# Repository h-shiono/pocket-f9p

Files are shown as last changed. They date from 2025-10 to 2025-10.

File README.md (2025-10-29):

# 📡 Pocket-F9P

`Pocket-F9P` is a pocketable, all-in-one high-precision GNSS (F9P) receiver with a battery, data logger, and BLE (NTRIP) interface.

> [!IMPORTANT]
> ⚠️ We shall not be held responsible for any damage or loss incurred as a result of actions taken based on the information contained in this repository. 

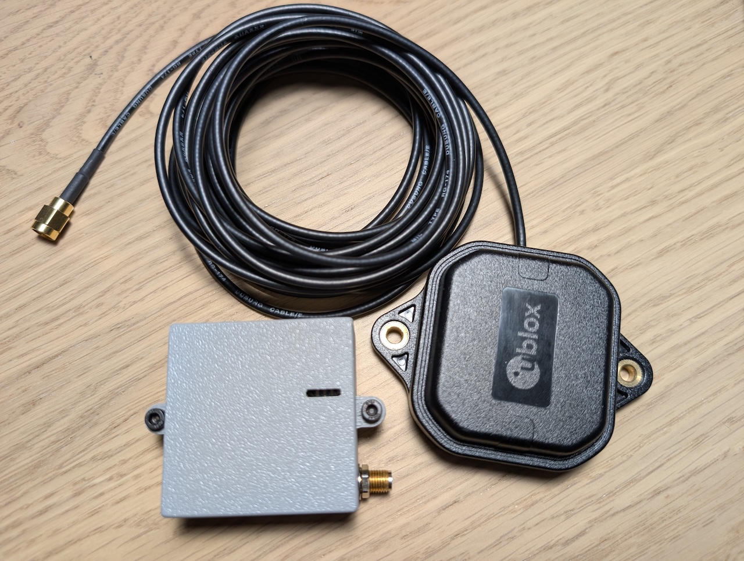
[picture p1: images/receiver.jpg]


[🇯🇵 README](README_jp.md)

## 🚀　Overview

- **Battery Driven, Compact, High-Accuracy GNSS Receiver:** Designed the compact (Approx. 48 mm x 48 mm x 22 mm) GNSS receiver to improve the usability of u-blox F9P, with Micro SD logger, communication and battery
- **Supports correction input via BLE:** By combining with the smartphone application such as `GNSS Master`, the receiver can utilize the correction data via `NTRIP`
- **Customizable microcontroller:** The microcontroller `Seeeduino XIAO` is utilized for the communication, so it’s easy to customize the application for user-dedicated objectives

**Important notes for use**
> [!WARNING]
> When you connect to the F9P usb port, you have to switch the hw switch `off`.
> The boards (`XIAO ESP32C`, `u-blox F9P` or both) will be damaged.

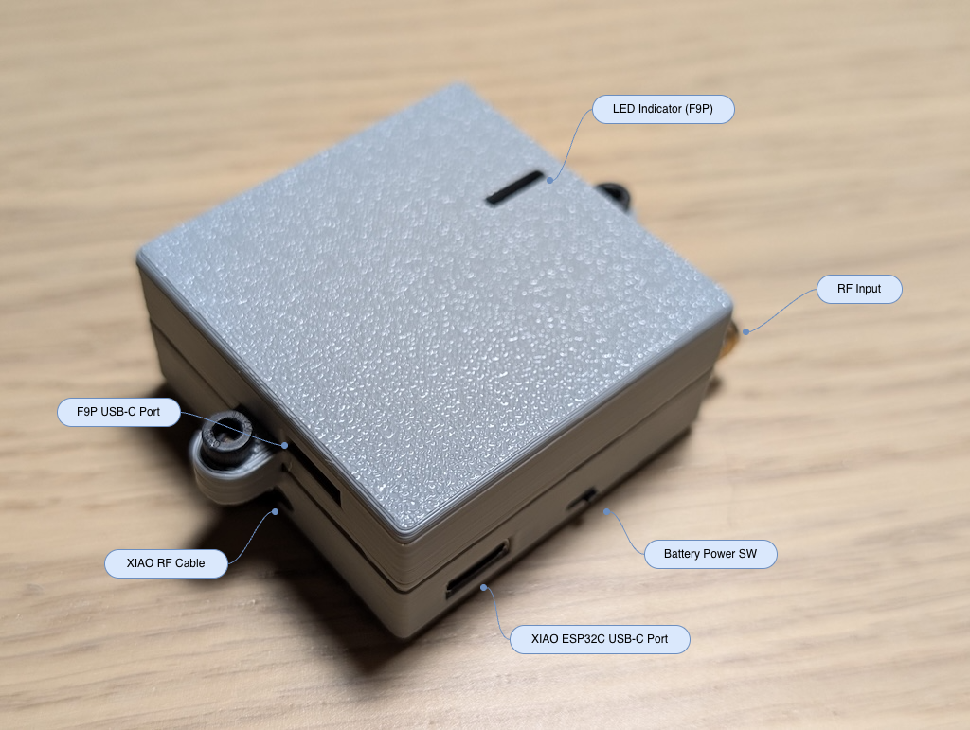
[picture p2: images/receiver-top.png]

<br>
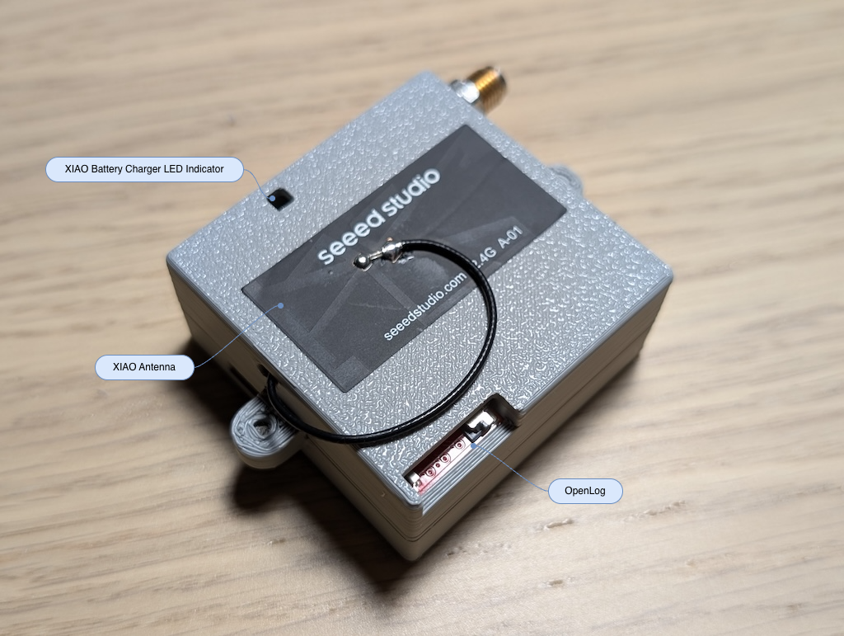
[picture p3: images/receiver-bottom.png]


## ⚙️ Setup

This section describes how to setup the receiver.

### Hardware

##### Parts list

Parts                                                                                                                       |Qty|Description
----------------------------------------------------------------------------------------------------------------------------|---|-----------
[SparkFun GPS-RTK2 Board - ZED-F9P (Qwiic)](https://www.sparkfun.com/sparkfun-gps-rtk2-board-zed-f9p-qwiic-gps-15136.html)  |1  |GNSS Receiver
[Seeeduino XIAO ESP32C](https://www.seeedstudio.com/Seeed-XIAO-ESP32C3-p-5431.html)                                         |1  |Battery charger and BLE/NTRIP Interface
[SparkFun OpenLog](https://www.sparkfun.com/sparkfun-openlog.html)                                                          |1  |Micro SD Logger
[DATA POWER TECHNOLOGY DTP652533](https://www.sengoku.co.jp/mod/sgk_cart/detail.php?code=EEHD-67JP)                         |1  |Battery
SMA to U.FL Cable                                                                                                           |1  |SMA <-> U.FL Conversion
[NKK Switches SS-12SDP2](https://www.nkkswitches.co.jp/product/detailed/SS-12SDP2.html)                                     |1  |HW Switch
M3 x 5                                                                                                                      |2  |To secure the case
M3 x 25                                                                                                                     |4  |**Optional, Recommended** To secure the exoskeleton
M3 Nut                                                                                                                      |4  |**Optional, Recommended** To secure the exoskeleton

> [!NOTE]
> We utilized [SwitchScience ZED-F9P搭載GPS-RTKピッチ変換基板](https://www.switch-science.com/products/10511?_pos=4&_sid=bce749730&_ss=r) receiver for the prototyping.

#### Print the case

This repository provides two case options:

**v0.1.0 (Standard)**
The original compact case. *Note: The BLE antenna is exposed.*

- [Pocket-F9P-Top.3mf](case/Pocket-F9P-Top.3mf): Upper (F9P)
- [Pocket-F9P-Center.3mf](case/Pocket-F9P-Center.3mf): Center frame
- [Pocket-F9P-Bottom.3mf](case/Pocket-F9P-Bottom.3mf): Bottom (Logger, XIAO, Battery, HW Switch)

**v0.2.0 (with Exoskeleton)**
Recommended. Includes an external frame to protect the BLE antenna and add robustness.

- [Pocket-F9P-Top.3mf](case/Pocket-F9P-Top.3mf): Upper (F9P)
- [Pocket-F9P-Center.3mf](case/Pocket-F9P-Center.3mf): Center frame
- [Pocket-F9P-Bottom.3mf](case/Pocket-F9P-Bottom.3mf): Bottom (Logger, XIAO, Battery, HW Switch)
- [Exoskeleton-Top.3mf](case/Exoskeleton-Top.3mf)
- [Exoskeleton-Bottom.3mf](case/Exoskeleton-Bottom.3mf)

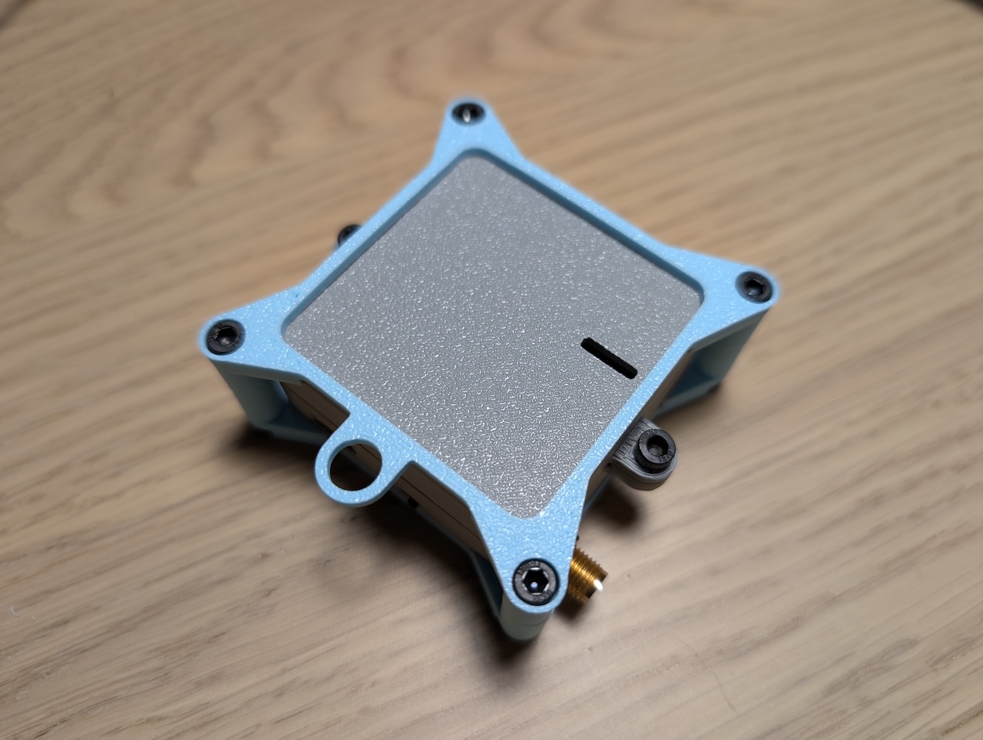
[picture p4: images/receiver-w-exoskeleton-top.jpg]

<br>
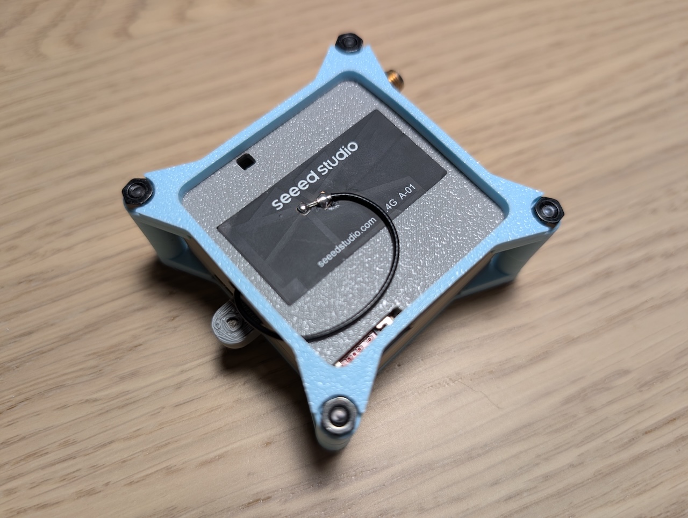
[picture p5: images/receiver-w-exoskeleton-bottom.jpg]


##### Wiring

Please refer to the following diagram and figure for wiring.

**Block Diagram**

```mermaid
graph TD

    sw[HW Switch]

    subgraph XIAO
        gnd_pad[GND Pad]
        vcc_pad[VCC Pad]
        d1["D1 (Tx)"]
        d2["D2 (Rx)"]
        xiao_vcc[3.3V]
        xiao_gnd[GND]
    end

    subgraph SW
        sw[SW] --- vcc_pad
    end

    subgraph Battery
        bat_minus[Bat -] --- gnd_pad
        bat_plus[Bat +] --- sw
    end

    subgraph Open-log
        ol_tx[Tx]
        ol_rx[Rx]
        ol_vcc[3.3V]
        ol_gnd[GND]
    end

    subgraph F9P-board
        tx_1[UART1 Tx] --- ol_rx
        rx_1[UART1 Rx] --- ol_tx
        tx_2[UART2 Tx] --- d2
        rx_2[UART2 Rx] --- d1
        f9_gnd[GND] --- ol_gnd 
        f9_vcc[3.3V] --- ol_vcc
        f9_gnd --- xiao_gnd
        f9_vcc --- xiao_vcc
    end
```

**Wiring Image**

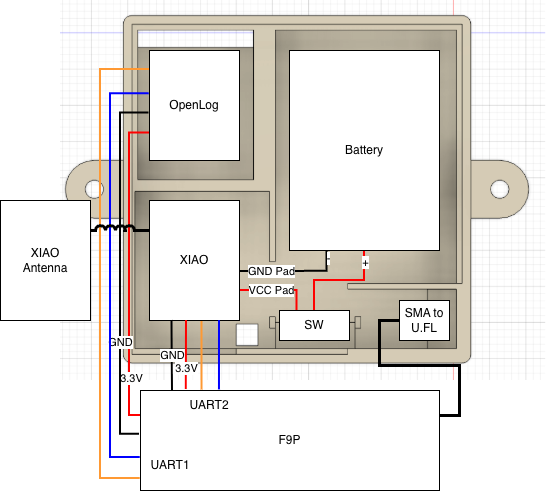
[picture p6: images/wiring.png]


#### Assembly

> [!CAUTION]
> We recommend [Write Firmware](#write-firmware) before assembling.

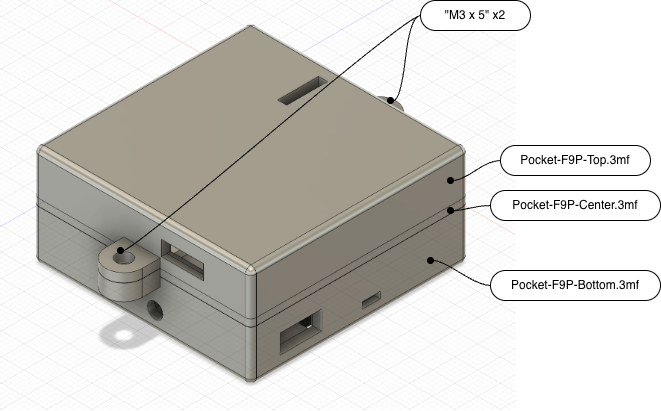
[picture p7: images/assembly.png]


### Software

#### Python setup

To setup the python environment, use uv:

```bash
cd pocket-f9p
uv sync
```

#### XIAO ESP32C

##### Write Firmware

1. **Download Firmware:** Download firmware from: [MicroPython ESP32-C3](https://micropython.org/download/ESP32_GENERIC_C3/), and move it to this directory
2. **Erase Flash:** Erase the flash by `erase-flash` option
3. **Write Firmware:** Then, write the binary which is downloaded in step 1 by `write-flash` option.

###### Erase Flash

```bash
% esptool --port /dev/cu.usbmodem1101 erase-flash 
sptool v5.1.0
Connected to ESP32-C3 on /dev/cu.usbmodem1101:
Chip type:          ESP32-C3 (QFN32) (revision v0.4)
Features:           Wi-Fi, BT 5 (LE), Single Core, 160MHz, Embedded Flash 4MB (XMC)
Crystal frequency:  40MHz
USB mode:           USB-Serial/JTAG
MAC:                94:a9:90:7a:07:f8

Stub flasher running.

Flash memory erased successfully in 14.9 seconds.

Hard resetting via RTS pin...
```

###### Write Firmware

```bash
% esptool --port /dev/cu.usbmodem1101 --baud 460800 write-flash 0 ESP32_GENERIC_C3-20250911-v1.26.1.bin
esptool v5.1.0
Connected to ESP32-C3 on /dev/cu.usbmodem1101:
Chip type:          ESP32-C3 (QFN32) (revision v0.4)
Features:           Wi-Fi, BT 5 (LE), Single Core, 160MHz, Embedded Flash 4MB (XMC)
Crystal frequency:  40MHz
USB mode:           USB-Serial/JTAG
MAC:                94:a9:90:7a:07:f8

Stub flasher running.
Changing baud rate to 460800...
Changed.

Configuring flash size...
Flash will be erased from 0x00000000 to 0x001cffff...
Wrote 1898384 bytes (1159203 compressed) at 0x00000000 in 14.3 seconds (1062.0 kbit/s).
Hash of data verified.

Hard resetting via RTS pin...
```

##### Write Script

After firmware writing, let's move on to the writing the application.

1. **Install Extension:** Install [MicroPico`](https://marketplace.visualstudio.com/items?itemName=paulober.pico-w-go) from MARKETPLACE
2. **Connect XIAO and Computer:** Connect XIAO and your computer with USB cable, then execute `Shift + >MicroPico: Connect` via `VS Code` command palette
3. **Write Script:** Open [main.py](src/pocket_f9p/main.py), then execute `Shift + >MicroPico: Upload file to pico` via command palette to upload the script to XIAO

#### u-blox F9P

The ports settings of F9P are as follows:

Target  |Protocol in            |Protocol out           |Baudrate   |Dest.
--------|-----------------------|-----------------------|-----------|-----
UART1   |0+1+5 - UBX+NMEA+RTCM3 |0+1+5 - UBX+NMEA+RTCM3 |115200     |Logger
UART2   |0+1+5 - UBX+NMEA+RTCM3 |**1 - NMEA**           |**38400**  |XIAO

> [!NOTE]
> - Our firmware supports **NMEA output only**
> - Set `1 - NMEA` for UART2 protocol out
>   - It is okay to set `0+1+5 - UBX+NMEA+RTCM3` for UART2 protocol out, however it's difficult to forward the whole data within 1 sec when using full GNSS constellations
> - We recommended the baudrate 38400bps, but the firmware can detect it automatically (supports 9600/38400/115200/57600/19200/230400 bps)

### 📱 Setup (Smartphone, Android)

#### Application (GNSS Master)

We utilized [GNSS Master](https://www.gnssmaster.com/) for this development.

##### GNSS Receiver Connection Setting

Tap ⚙️ on the right side of `GNSS Receiver Connection`, and set the following:

- **Mode:** `Bluetooth LE`
- **Paired Devices:** `Pocket-F9P`

##### Correction Input Setting

Tap ⚙️ on the right side of `Correction Input`, and setting it if needed.

##### Receiver Data Output Setting

Tap ⚙️ on the right side of `Receiver Data Output`, and setting it if needed.

#### Other settings (Developer Mode, etc.)

- **Enabling Developer mode:** see [Configure on-device developer options](https://developer.android.com/studio/debug/dev-options?hl=en)
- **Select mock location app:** see [Debugging](https://developer.android.com/studio/debug/dev-options?hl=en#debugging)

## 📖 How to use?

### Basic usage

1. **Power on the receiver:** 
    - Battery Driven: Switch `ON` the HW Switch
    - Using USB Bus Power: Connect the usb cable to the `XIAO`'s port, if you want to charge the battery, you should switch `ON` the HW switch as well
2. **Start GNSS Master and Connect to the receiver:** see [GNSS Receiver Connection Setting](#gnss-receiver-connection-setting)
3. **Connect the Correction Input (If needed):** see [Correction Input Setting](#correction-input-setting)

## 🧠 LLM Utilization

- Design Review: Gemini
- Coding Assistant: Claude (Anthropic)

## 🤝 Contributing

We welcome bug reports, feature suggestions and pull requests.

1.  Please create an issue to report the problem.
2.  When submitting the PR, clearly describe the changes made.

## ⚠️ Known Issues & Limitations

- **Prototype Quality:** This HW and SW are prototype, therefore we have not performed sufficient verification
    - **XIAO Antenna Exposure:** The XIAO's BLE antenna and its cable are exposed on the outside of the case. This poses a risk to long-term robustness and potential snagging of the cable. (✅ `v0.2.0`: Add exoskeleton frame)
- **Application Dependency:** We checked the application compatibility only with `GNSS Master`
- **NTRIP Correction:** We have not verified the NTRIP correction
- **Regarding GNSS Status view in GNSS Master:** We confirmed the following issues, but we do not verify the further details:
    - The UTC time does not update for several seconds
    - Sometimes `No NMEA RMC` is shown

## 📄 License

This project is licensed under the [MIT License](LICENSE).
(3D data files are licensed under [CC BY-SA 4.0](https://creativecommons.org/licenses/by-sa/4.0/))

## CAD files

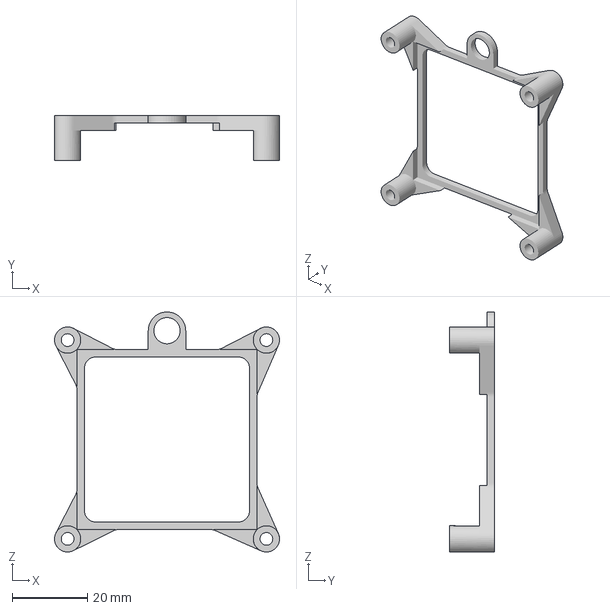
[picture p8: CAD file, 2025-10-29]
case/Exoskeleton-Top.3mf
60.0 x 12.0 x 64.0 mm

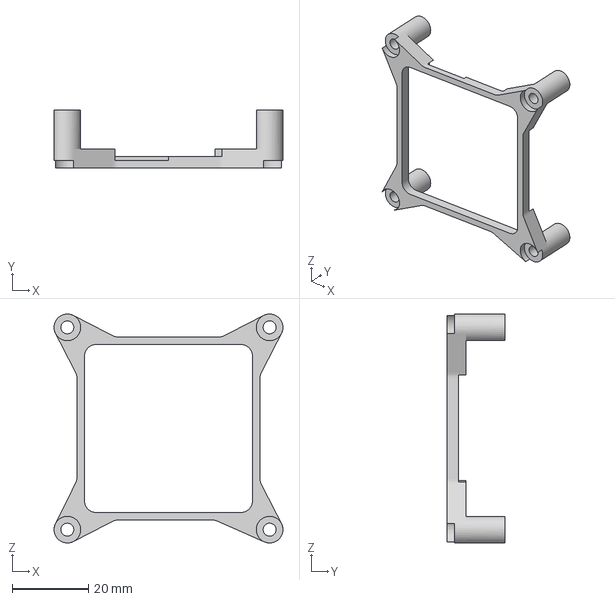
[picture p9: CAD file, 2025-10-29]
case/Exoskeleton-Bottom.3mf
60.0 x 15.2 x 60.0 mm

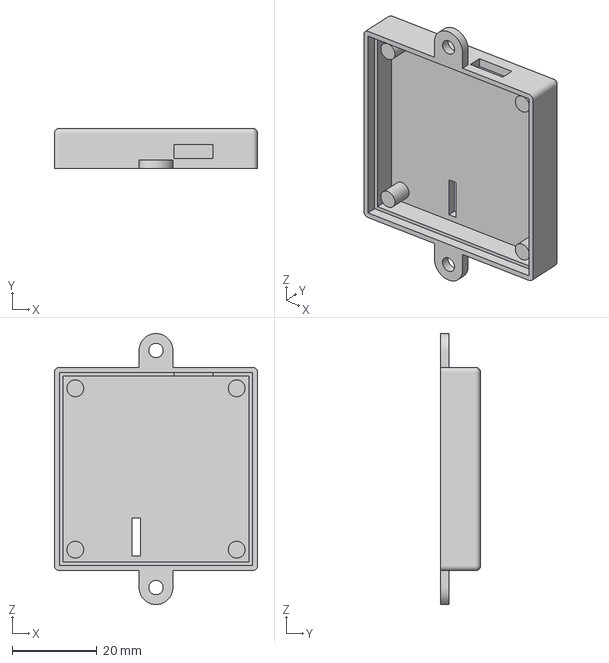
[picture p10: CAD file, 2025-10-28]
case/Pocket-F9P-Top.3mf
48.0 x 9.50 x 64.0 mm

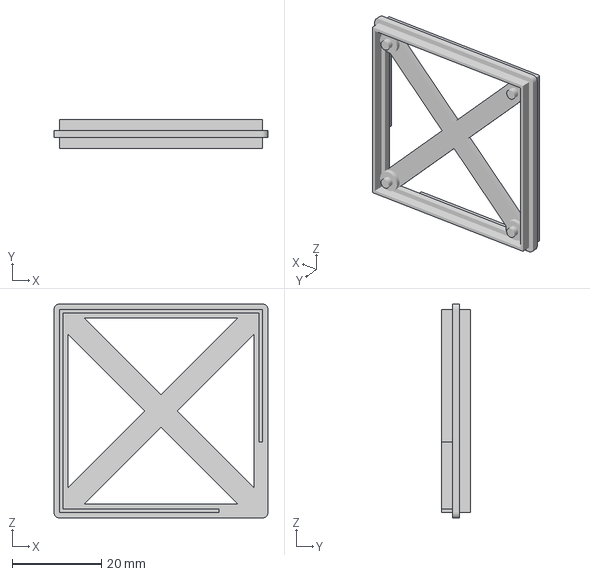
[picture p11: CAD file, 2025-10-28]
case/Pocket-F9P-Center.3mf
48.0 x 6.40 x 48.0 mm

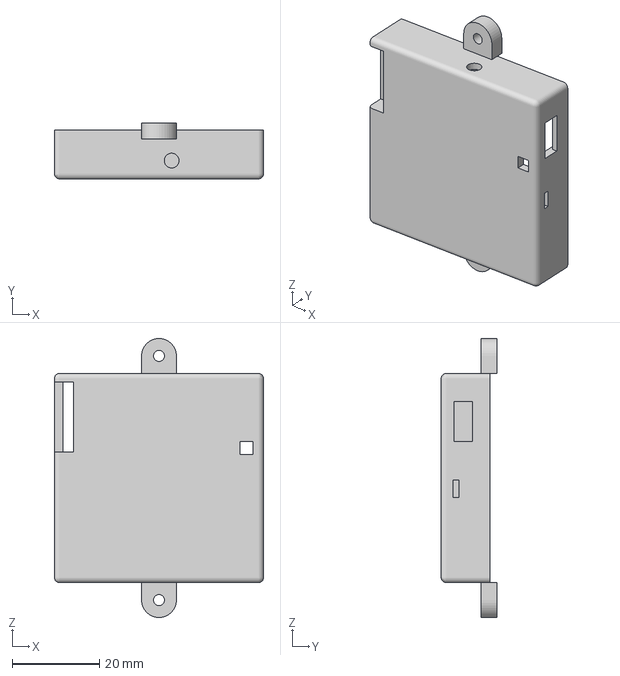
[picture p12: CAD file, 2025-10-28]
case/Pocket-F9P-Bottom.3mf
48.0 x 12.8 x 64.0 mm

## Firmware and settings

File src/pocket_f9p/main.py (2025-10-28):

import struct
import time

import ubluetooth
from machine import UART, Pin

XIAO_TX_PIN = 2  # XIAO D1 (GPIO2)
XIAO_RX_PIN = 3  # XIAO D2 (GPIO3)

# Common baudrates for u-blox F9P (in priority order)
# 38400 is tried first as it's the configured baudrate
BAUDRATES = [38400, 9600, 115200, 57600, 19200, 230400]

# UART settings for u-blox F9P
# XIAO D1 (GPIO2 / TX) -> F9P RX
# XIAO D2 (GPIO3 / RX) -> F9P TX
uart = None


def detect_baudrate():
    """Detect F9P baudrate by trying common rates"""
    global uart

    for baudrate in BAUDRATES:
        print(f"Trying baudrate: {baudrate}...")
        uart = UART(
            1,
            baudrate=baudrate,
            tx=Pin(XIAO_TX_PIN),
            rx=Pin(XIAO_RX_PIN),
            rxbuf=2048,
            timeout=100,
        )

        # Wait for data - check multiple times over 2 seconds
        # (NMEA messages typically sent at 1Hz)
        total_bytes = 0
        for i in range(4):  # Check 4 times over 2 seconds
            time.sleep_ms(500)
            bytes_available = uart.any()
            total_bytes = max(total_bytes, bytes_available)

        # Read and check if it looks like NMEA data
        if total_bytes > 10:  # Need substantial data to verify
            test_data = uart.read(min(total_bytes, 200))

            # Check for NMEA sentences (start with $)
            # NMEA should be mostly printable ASCII
            if test_data and b"$" in test_data:
                printable_count = sum(
                    1 for b in test_data if 32 <= b <= 126 or b in [10, 13]
                )
                printable_pct = (
                    (100 * printable_count // len(test_data))
                    if len(test_data) > 0
                    else 0
                )

                # NMEA should be 80%+ printable characters
                if printable_pct >= 80:
                    print(f"  -> Detected NMEA data at {baudrate} bps")
                    # Clear the buffer by reading remaining data
                    if uart.any() > 0:
                        uart.read()
                    return baudrate

        uart.deinit()

    # Fallback to 38400 (configured baudrate)
    print("Could not detect baudrate, defaulting to 38400")
    uart = UART(
        1,
        baudrate=38400,
        tx=Pin(XIAO_TX_PIN),
        rx=Pin(XIAO_RX_PIN),
        rxbuf=2048,
        timeout=100,
    )
    return 38400


print("Detecting F9P baudrate...")
detected_baudrate = detect_baudrate()
print(f"Using baudrate: {detected_baudrate}")

# BLE settings (Nordic UART Service - NUS)
BLE_NAME = "Pocket F9P"
_IRQ_CENTRAL_CONNECT = 1
_IRQ_CENTRAL_DISCONNECT = 2
_IRQ_GATTS_WRITE = 3

# NUS Definitions
_UART_UUID = ubluetooth.UUID("6E400001-B5A3-F393-E0A9-E50E24DCCA9E")
_UART_TX_CHAR_UUID = ubluetooth.UUID("6E400003-B5A3-F393-E0A9-E50E24DCCA9E")
_UART_RX_CHAR_UUID = ubluetooth.UUID("6E400002-B5A3-F393-E0A9-E50E24DCCA9E")

# Define the UART service
uart_service = (
    _UART_UUID,
    (
        (_UART_TX_CHAR_UUID, ubluetooth.FLAG_NOTIFY),
        (_UART_RX_CHAR_UUID, ubluetooth.FLAG_WRITE | ubluetooth.FLAG_WRITE_NO_RESPONSE),
    ),
)

ble = ubluetooth.BLE()
ble.active(True)

# Register the service
((tx_handle, rx_handle),) = ble.gatts_register_services((uart_service,))

# Set buffer sizes
ble.gatts_set_buffer(rx_handle, 512, True)
ble.gatts_set_buffer(tx_handle, 512, True)

# connection handle
conn_handle_global = None


# BLE callback function
def ble_irq(event, data):
    global conn_handle_global

    if event == _IRQ_CENTRAL_CONNECT:
        # Connected to a smartphone
        conn_handle, _, _ = data
        conn_handle_global = conn_handle
        print("BLE Connected")

    elif event == _IRQ_CENTRAL_DISCONNECT:
        # Disconnected from smartphone
        conn_handle_global = None
        print("BLE Disconnected")
        # Restart advertising (waiting for connection)
        advertise()

    elif event == _IRQ_GATTS_WRITE:
        # Data written from smartphone (RTCM correction data)
        conn_handle, value_handle = data
        if conn_handle == conn_handle_global and value_handle == rx_handle:
            # Read data from BLE
            data_received = ble.gatts_read(rx_handle)
            print(f"Received {len(data_received)} bytes from BLE, writing to F9P UART")

            bytes_written = uart.write(data_received)
            if bytes_written is None or bytes_written < len(data_received):
                print("Warning: Not all data was written to UART")


# Register the BLE event handler
ble.irq(ble_irq)


# Advertising payload helper (minimal: flags + complete local name)
def advertising_payload(name=None):
    # Flags: LE General Discoverable Mode, BR/EDR not supported
    payload = bytearray(b"\x02\x01\x06")
    if name:
        name_bytes = name.encode()
        payload += struct.pack("BB", len(name_bytes) + 1, 0x09) + name_bytes
    return payload


# Start advertising
def advertise():
    payload = advertising_payload(name=BLE_NAME)
    ble.gap_advertise(100000, adv_data=payload)
    print(f"Advertising as '{BLE_NAME}'...")


advertise()

# Main loop
# F9P to Smartphone data forwarding (NMEA only)
print("Main loop starting. Waiting for BLE connection...")
print(
    f"UART initialized: baudrate={detected_baudrate}, tx=GPIO{XIAO_TX_PIN}, rx=GPIO{XIAO_RX_PIN}"
)

loop_count = 0
while True:
    # Debug: Print status every 5 seconds
    loop_count += 1
    if loop_count % 250 == 0:  # 250 * 20ms = 5 seconds
        bytes_available = uart.any()
        print(
            f"Status: BLE={'Connected' if conn_handle_global else 'Disconnected'}, UART buffer={bytes_available} bytes"
        )

    if conn_handle_global is not None:
        # Check if data available from F9P
        bytes_available = uart.any()
        if bytes_available > 0:
            # Read NMEA data from F9P
            nmea_data = uart.read(bytes_available)
            if nmea_data and len(nmea_data) > 0:
                try:
                    # Forward all NMEA data via BLE
                    ble.gatts_notify(conn_handle_global, tx_handle, nmea_data)
                    print(f"Forwarded {len(nmea_data)} bytes NMEA to BLE")
                except OSError as e:
                    # Connection lost
                    print(f"Error: BLE connection lost during notify: {e}")

    time.sleep_ms(20)

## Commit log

2025-10-28 Implement BLE UART service for F9P data forwarding
2025-10-28 Refactor UART initialization and enhance NMEA data filtering for F9P integration
2025-10-28 Add 3D model files for Pocket F9P case components
    [Pocket-F9P-Bottom.3mf, Pocket-F9P-Center.3mf, Pocket-F9P-Top.3mf]
2025-10-28 Implement data forwarding modes (NMEA, RAW, UBX) and BLE command handling for mode switching
2025-10-28 Refactor README and main.py for simplified NMEA data handling
    - Updated README.md to clarify UART2 settings and NMEA output only.
    - Removed complex data transfer modes (NMEA/RAW/UBX) from main.py.
    - Simplified baud rate detection to prioritize 38400 bps.
    - Streamlined data forwarding to only handle NMEA sentences.
    - Removed unnecessary diagnostic and filtering logic for improved performance.
2025-10-28 Add new images for receiver components
    - Added receiver-bottom.png
    - Added receiver-top.png
    - Added receiver.jpg
    - Added wiring.png
2025-10-28 Add assembly figure
2025-10-29 Fix firmware writing link and add note on XIAO antenna issues in README
2025-10-29 Update README and add exoskeleton case options with images
    [Exoskeleton-Bottom.3mf, Exoskeleton-Top.3mf]
